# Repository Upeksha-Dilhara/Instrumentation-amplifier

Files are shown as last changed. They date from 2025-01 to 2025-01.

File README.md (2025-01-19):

# Instrumentation Amplifier for Thermocouple

This repository contains the design and implementation of an instrumentation amplifier tailored for thermocouple applications. The project was developed as part of the **EN3533 - Electronic Instrumentation** course at the **University of Moratuwa**. 

The goal of this project is to design an accurate and reliable instrumentation amplifier (IN-AMP) to amplify small voltage signals generated by thermocouples, ensuring precise temperature measurement. 
The amplifier is optimized to reject noise and maintain signal integrity in various industrial and scientific applications.

## Key Features
<p align="justify"> This project focuses on the amplification of weak thermoelectric signals generated by K-type thermocouples. The instrumentation amplifier design ensures effective noise rejection through a high common-mode rejection ratio (CMRR). It incorporates high input impedance, which allows for accurate readings without causing loading on the signal source. The printed circuit board (PCB) is optimized to minimize electromagnetic interference (EMI) and features precise signal routing. Additionally, the design includes a built-in cold-junction compensation mechanism for accurate temperature measurements. </p>

## Introduction
<p align="justify">Thermocouples are temperature sensors that operate based on the Seebeck effect, which generates a proportional voltage when there is a temperature difference between two dissimilar metals. K-type thermocouples, which are widely used in this project, are recognized for their wide temperature range (0°C to 1300°C), rugged design, and near-linear output voltage. To amplify the weak voltage signals generated by these thermocouples, instrumentation amplifiers (IN-AMPs) are used. These specialized amplifiers excel at amplifying small signals with high accuracy, rejecting noise and interference, and maintaining signal integrity through high input impedance and low output impedance. In thermocouple applications, where signals are often weak and susceptible to noise, an IN-AMP ensures reliable and precise amplification.</p>

## Specifications
- **Thermocouple Type**: K-type
- **Temperature Range**: 0°C to 1300°C
- **Output Voltage**: 0–55 mV
- **Sensitivity**: ~41 µV/°C
- **Selected IN-AMP**: AD8495
- **Amplifier Gain**: Fixed at 122 dB
- **Power Supply Voltage**: +5V
- **Output Sensitivity**: 5 mV/°C

## Design Process
### Schematic Design
<p align="justify">The schematic design involves several key components, including a thermocouple connector with ground shielding, the AD8495 instrumentation amplifier, and filtering components such as resistors and capacitors for noise rejection. Decoupling capacitors are placed near the power supply pins to ensure stable operation. Differential inputs are routed with equal PCB trace lengths for signal integrity, while noise filtering is achieved using carefully chosen RC networks. </p>

- Differential filter cutoff frequency: \( f_{\text{DIFF}} = \frac{1}{2 \pi R (2C_D + C_C)} \)
- Common-mode filter cutoff frequency: \( f_{\text{CM}} = \frac{1}{2 \pi R C_C} \)


### PCB Design
<p align="justify">The PCB design employs a two-layer board measuring 22mm by 33mm. The top layer is allocated for power lines with a width of 20 mil and signal tracks with a width of 10 mil, while the bottom layer serves as a ground plane to minimize EMI. Components are strategically positioned close to the thermocouple connections to ensure accurate cold-junction compensation. Differential pair routing is utilized for positive and negative input signals, and the design was verified using Altium's design rule checker. The PCBs were manufactured by JLCPCB.</p>





<p align="justify">The fabrication adhered to specific constraints, including a minimum trace width of 10 mil, a minimum via diameter of 20 mil, and a minimum track spacing of 10 mil. Components were sourced from Mouser Electronics and assembled manually using soldering tools, ensuring high-quality construction of the PCB.</p>

## Testing and Results
- **Testing Environment**:
  - Ambient temperature conditions.
  - K-type thermocouple connected to a controlled heat source.
- **Key Metrics**:
  - Noise rejection validated using a signal generator and oscilloscope.
  - Output voltage measured across a range of temperatures.
  - Results matched expected sensitivity of 5 mV/°C.
- **Observations**:
  - High stability and accuracy in measurements.
  - Effective noise rejection in noisy industrial-like environments.

For further details, refer to the [Instrumentation_Amplifier_for_thermo_couple_Report.pdf](https://github.com/user-attachments/files/18468705/Instrumentation_Amplifier_for_thermo_couple_Report.pdf)

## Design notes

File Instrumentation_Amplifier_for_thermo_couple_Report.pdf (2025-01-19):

### Department of Electronic and Telecommunication Engineering

## University of Moratuwa, Sri Lanka

## EN3533 - ELECTRONIC INSTRUMENTATION

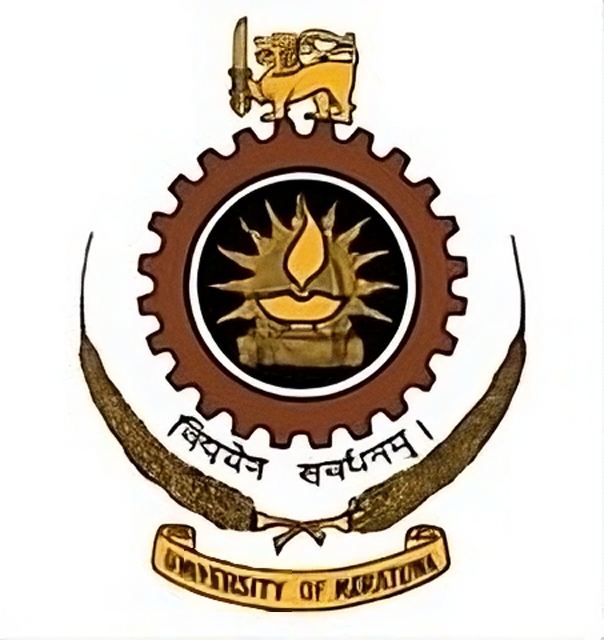
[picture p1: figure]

# Instrumentation Amplifier for Thermo-couple

# Group Members

DILHARA A.D.U | - | 200128D
FERNANDOPULLE N.K - | 200172F
SHEHAN H.M.K | - | 200601X

# Contents

## 0.1 Introduction

In this project, we have designed an Instrumentation amplifier specifically tailored for thermocouple applications. The report provides a comprehensive overview, including basic information about thermocouples and instrumentation amplifiers. It outlines the meticulous design process, encompassing component selection, amplifier configuration, and testing procedures employed to achieve accurate amplification of thermoelectric signals. The report also includes detailed schematics, PCB layouts, and insights into the amplifier selec-

tion process, offering readers a holistic understanding of the project.

### 0.1.1 Thermocouples and applications

Thermocouples are temperature sensors widely used in various industrial, scientific, and commercial applications due to their reliability and simplicity. Operating principle of thermocouples based on the Seebeck effect, where a temperature difference between two dissimilar metals generates a voltage proportional to the temperature change. The subtopic covers different types of thermocouples, such as K-type, J-type, and T-type, each suited for specific temperature ranges and environments.

Real-world applications of thermocouples are explored, ranging from industrial processes and HVAC systems to aerospace and scientific research. Detailed examples illustrate how thermocouples are utilized in diverse settings, showcasing their adaptability and effectiveness in measuring temperatures under varying conditions.

### 0.1.2 Introduction to Instrumentation amplifiers

Instrumentation amplifiers (In-amps) are specialized operational amplifiers (op-amps) designed to amplify small signals with high precision and accuracy, particularly in noisy environments. Unlike general-purpose op-amps, instrumentation amplifiers are specifically engineered for applications where signal integrity is critical, such as in sensor measurements and data acquisition systems.
What sets instrumentation amplifiers apart is their ability to provide high input impedance, high common-mode rejection ratio (CMRR), and low output impedance. These characteristics make them ideal for amplifying weak signals while rejecting common-mode noise, ensuring that the amplified output accurately represents the desired signal.
Instrumentation amplifiers typically consist of multiple operational amplifiers and precision resistors configured in specific ways to achieve high performance. They offer differential inputs, allowing the amplification of the voltage difference between two input signals. In-amps are commonly used in various fields, including industrial automation, medical instrumentation, and scientific research, where accurate measurement of small signals is crucial.

### 0.1.3 Need for an INAMP in thermo-couple applications

In thermocouple-based applications, accurate temperature measurement is paramount. Thermocouples generate small voltage signals proportional to temperature changes, which are susceptible to interference and noise. Instrumentation amplifiers play a crucial role by precisely amplifying these weak signals while rejecting common-mode noise. Their high input impedance and excellent common-mode rejection properties ensure the fidelity of temperature readings, making them indispensable in thermocouple circuits. By enhancing signal integrity, instrumentation amplifiers enable reliable and precise temperature measurements, making them essential components in thermocouple-based systems used across various industries and scientific research.

## 0.2 Thermo-couple Specifications

### 0.2.1 Operating Principles and Parameters

A thermocouple is a device made by two different wires joined at one end, called junction end or measuring end. The two wires are called thermoelements or legs of the thermocouple: the two thermoelements are distnguished as positive and negative ones. The other end of the thermocouple is called tail end or reference end (Figure1). The junction end is immersed in the enviroment whose temperature T2 has to be measured, which can be for instance the temperature of a furnace at about 500°C, while the tail end is held at a different temperature T1, e.g. at ambient temperature.

Figure 1: Schematic drawing of a thermo-couple

Because of the temperature difference between junction end and tail end a voltage difference can be measured between the two thermoelements at the tail end: so the thermocouple is a temperature-voltage transducer.

However, it can be understood that the Emf depends on both T1 and T2: as T1 and T2 can change indipendently, a monotonic Emf vs T2 relationship cannot be defined if the tail end temperature is not constant. For this reason the tail end is mantained in an ice bath made by crushed ice and water in a Dewar flask: this produces a reference temperature of 0°C. All the voltage versus temperature relationships for thermocouples are referenced to 0°C. In a thermo-couple, measuring end is called as Hot junction and the tail end (reference junction) is called as Cold junction.

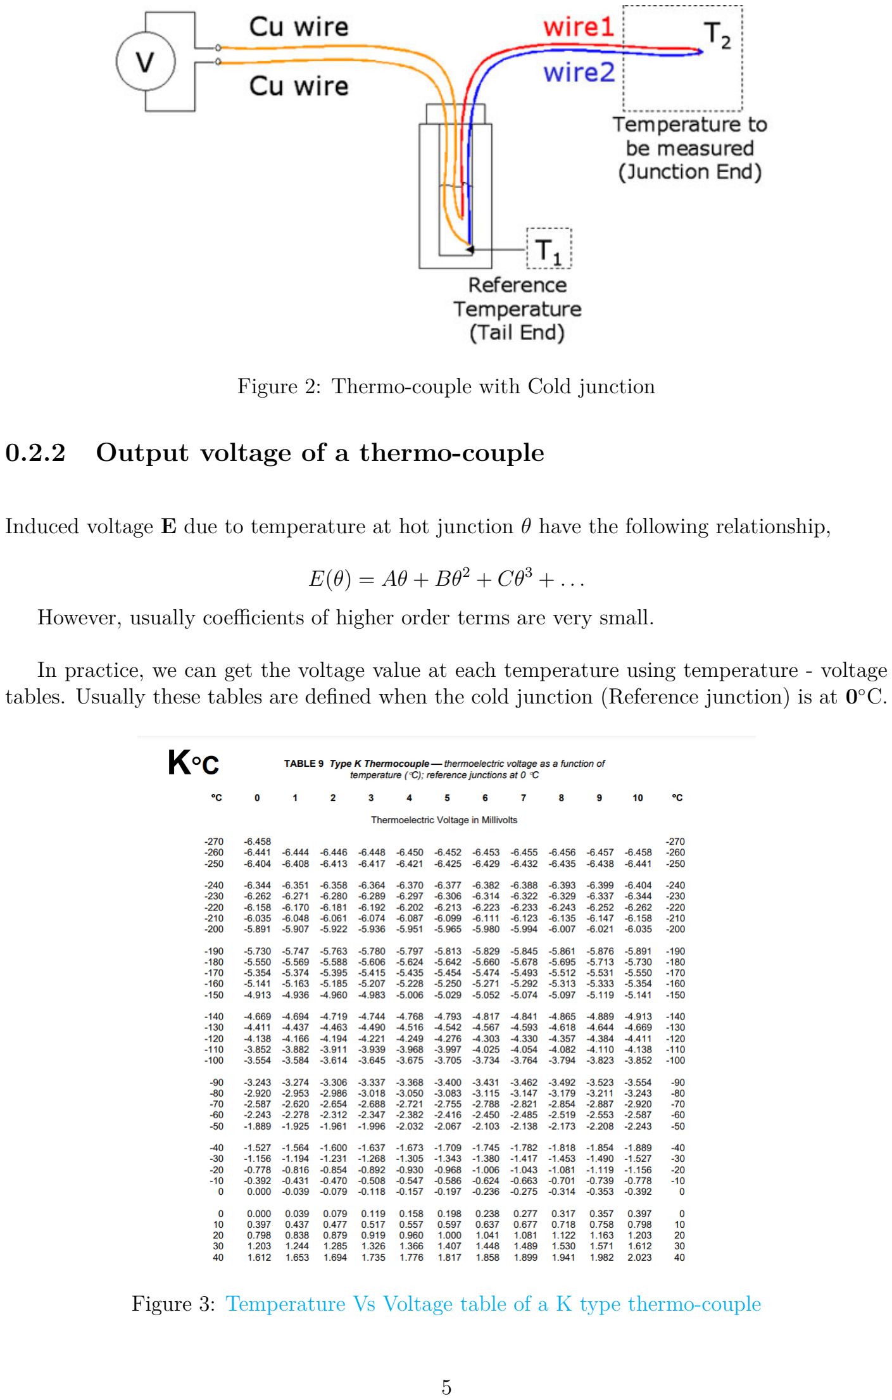
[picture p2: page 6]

Figure 2: Thermo-couple with Cold junction

### 0.2.2 Output voltage of a thermo-couple

Induced voltage E due to temperature at hot junction θ have the following relationship,

E(θ) = Aθ + Bθ² + Cθ³ + . . .

However, usually coefficients of higher order terms are very small.

In practice, we can get the voltage value at each temperature using temperature - voltage tables. Usually these tables are defined when the cold junction (Reference junction) is at 0

◦C.

Figure 3: Temperature Vs Voltage table of a K type thermo-couple (https://www.pyromation.com/downloads/data/emfk_c.pdf)

### 0.2.3 Selection of a thermo-couple

For our design, we have selected K Type thermo-couple due to its wide range of temperatures. One of the major advantage of K type thermocouple over other thermocouple’s is it can function in rugged environmental condition & in various atmospheres. Two wires of K type thermocouple are made from Alumel and Chromel alloys.

Another major importance is output voltage of K type thermocouple is almost linear with the temperature. (Linearity)

Specifications of K type thermo-couple

- Temperature Range | - 0 to 1300◦C (Can be used for negative temperatures also)
- Output voltage | - 0 to 55 mV
- Sensitivity | - Approximately 41µV/◦C

## 0.3 Instrumentation Amplifiers

Instrumentation amplifiers (Referred as IN-AMP) are specialized operational amplifiers that play a pivotal role in enhancing the accuracy and reliability of thermocouple measurements. By precisely amplifying weak thermoelectric signals while rejecting common-mode noise, these amplifiers ensure the fidelity of temperature data.

### 0.3.1 Operation of IN-AMPS

Three operational amplifiers (Op-Amps) and a number of precisely arranged resistors are needed to operate an instrumentation amplifier in order to produce the required amplification characteristics. An IN-AMP typically has three stages in its configuration:

- Differential Amplifier Stage: Two inputs receive the input signal differently. An initial differential amplifier that amplifies the voltage difference between these inputs is typically used in the first stage.
- Buffer Stages: After the differential amplifier are two buffer amplifiers, which are frequently constructed using operational amplifiers. Gain adjustment, low output impedance, and high input impedance are all made possible by these buffers. Additionally, they improve the overall performance by enabling the isolation of the gain-setting resistors from the source impedance.
- Gain Control: External precision resistors are usually used to set the gain of the IN-AMP and can be adjusted based on the needs of the application.

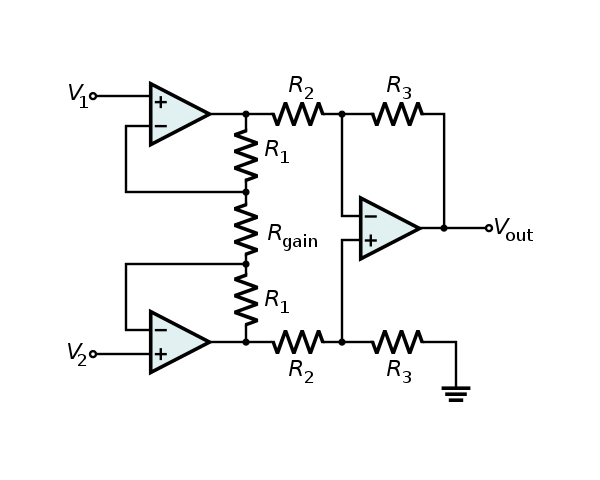
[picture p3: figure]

Figure 4: Basic Instrumentation amplifier

Since operational amplifiers normally have very high input impedance, two OP-amps at the input provides very high input impedance. Output voltage is given by ,

Vout =

1 +

2R1

Rgain !
R3
R2

By adjusting the Rgain properly, we can control the gain of the instrumentation amplifier.

### 0.3.2 Signal Conditioning using IN-AMP

Signal conditioning using instrumentation amplifiers (IN-AMPS) is a crucial aspect in various fields where precise signal manipulation is necessary to enhance the accuracy of measurements or sensor data.

- Amplification and Gain Control

With their high differential gain and ability to precisely magnify the difference between two input signals, IN-AMPS are invaluable tools for amplifying weak signals. The simplicity of gain control, which is accomplished by using external resistors, is their main feature. Because of its adaptability, amplification can be customized to meet the needs of individual applications, guaranteeing accurate and regulated signal enhancement.

- Noise Rejection

The remarkable ability of IN-AMPS to reject common-mode noise is a crucial component. They are excellent at reducing noise or interference that is equally present on both inputs while enhancing the differences between the input signals. This ability to reject noise is essential in applications where the signal of interest is frequently overshadowed by background noise.

- Filtering and Conditioning

IN-AMPS can be easily combined with other circuitry to offer conditioning and filtering of signals. By combining resistors, capacitors, and filters, they effectively cut out undesirable frequencies and modify the circuit response to fit the particular requirements of the application.

- High Input Impedance

Because of their high input impedance and low current consumption, IN-AMPS shield the signal source from loading effects. This quality guarantees precise measurements, which is critical in many applications where accuracy is critical.

- Precision Measurements

IN-AMPS are essential for sensor data acquisition applications like strain gauges, temperature, pressure, and bio-signal monitoring. They precisely boost these tiny sensor signals, improving measurement accuracy and dependability.

- Data Acquisition Systems

Before analog-to-digital conversion, signals gathered from a variety of sensors are conditioned by IN-AMPS, which are essential parts of data acquisition systems. Their involvement affects the dependability and quality of the collected data by guaranteeing the optimization of signals for precise and accurate digital representation.

### 0.3.3 Design requirements

In order to make our thermocouple measurement system effective and competitive, we looked at existing temperature controllers in the market. By understanding their features, we established specific design needs for our project. These requirements act as our project’s foundation, guiding us to create a system that meets user expectations and industry standards. We mainly referred the Omoron temperature controllers datasheets to get an idea for design requirements.

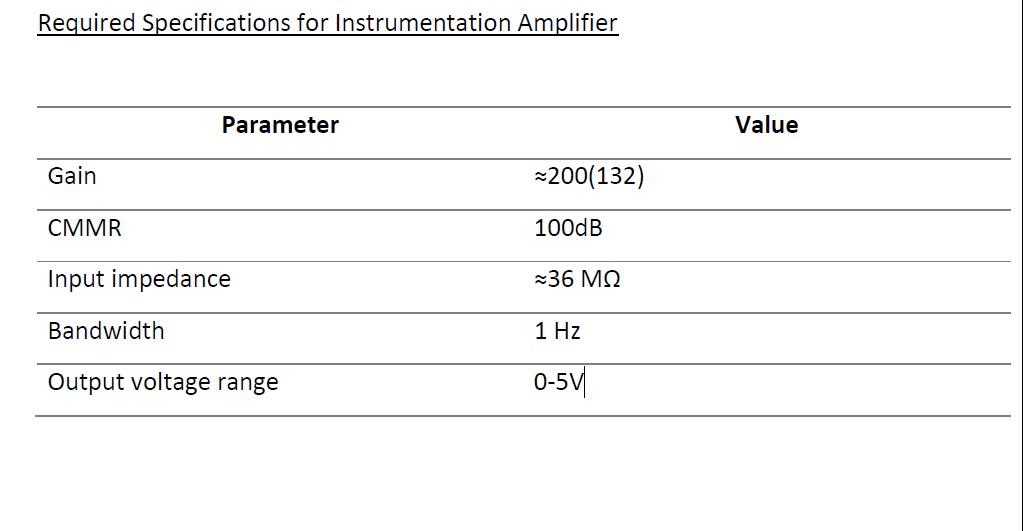
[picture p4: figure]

Figure 5: Requirements for the IN-AMP

### 0.3.4 Selection of a IN-AMP for the design

For the selection of an instrumentation amplifier (IN-AMP) for our design project, each of our group members individually researched and identified several op-amp ICs. The ICs we considered for our project include the AD8495, AMP04, and INA821. To determine the best IC for our instrumentation amplifier, we established specific criteria and assigned marks to each IC based on those criteria. The table below summarizes the marks obtained by each IC.

### Selection criteria

1. Input voltage range
2. Output voltage range
3. Gain
4. Input Impedance
5. CMRR
6. Bandwidth

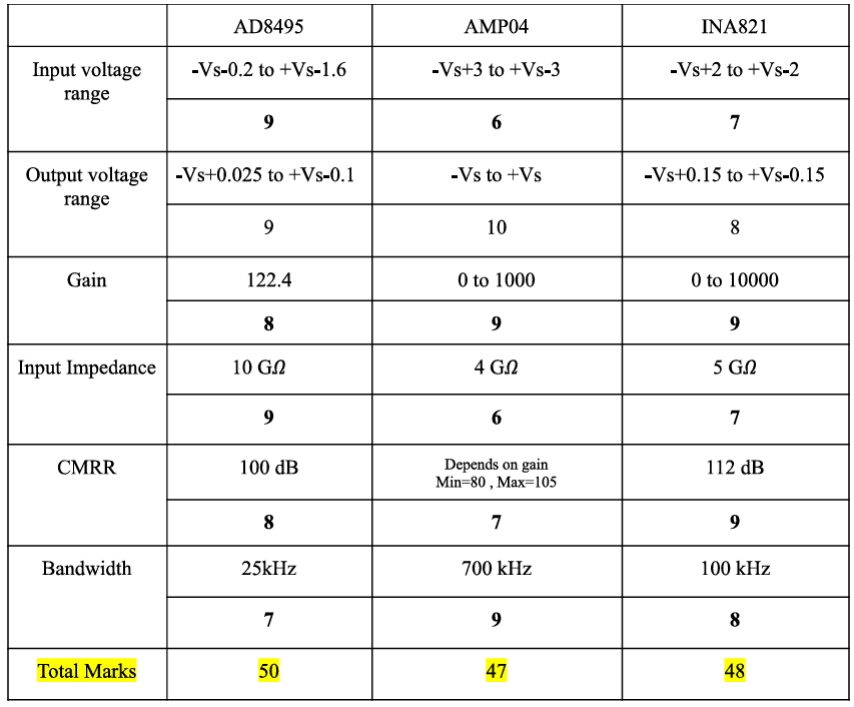
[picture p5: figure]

Figure 6: Selection criteria for IN-AMP selection

### Grounding and Shielding recommendations

In order to select the best IC for our design, we also considered the grounding and shielding recommendations given in the datasheet of each IC. By adhering to these guidelines, we can confidently anticipate optimal performance, minimal interference, and overall reliability in our final design.

Criterion | AD8495 | AMP04 | INA821
Grounding | Given properly with diagrams, Single ground is suffient at input to avoid ground loops. | Not properly mentioned | Provided proper component placement. But no much detail about grounding practices.
Shielding | Ground planes and power planes have been used in layouts. | Recommends to use shielded cables at input , twisted pairs | Recommends to keep proper trace spaces
Recommend Layouts | Evaluation board for the IC are available by same manufacturer. It can be used as reference. | Not given | Provided recommend layout practices and component placement guidline
Marks | 9 | 5 | 8

Table 1: Selection criteria for IN-AMP selection

By considering the Marks allocated in the selection Matrix and the best grounding and shielding methods given in the datasheets, AD8495 is the selected best Instrumentation amplifier for our thermocouple application.

## 0.4 Design Process

In the Design Process section, we outline the systematic approach undertaken to create our thermocouple measurement system. Above established guidelines and considering the specific requirements of the selected thermocouple and instrumentation amplifier, this phase focused on meticulous schematic design and precise PCB layout. By adhering to these guidelines, our team ensured the integration of key components for accurate and reliable temperature measurements. For the Schematic and PCB design, we used Altium PCB designer software.

### 0.4.1 Schematic Design

In the schematic design, our focus was on translating theoretical concepts into a practical and functional circuit. Guided by the unique requirements of our selected thermocouple and instrumentation amplifier.

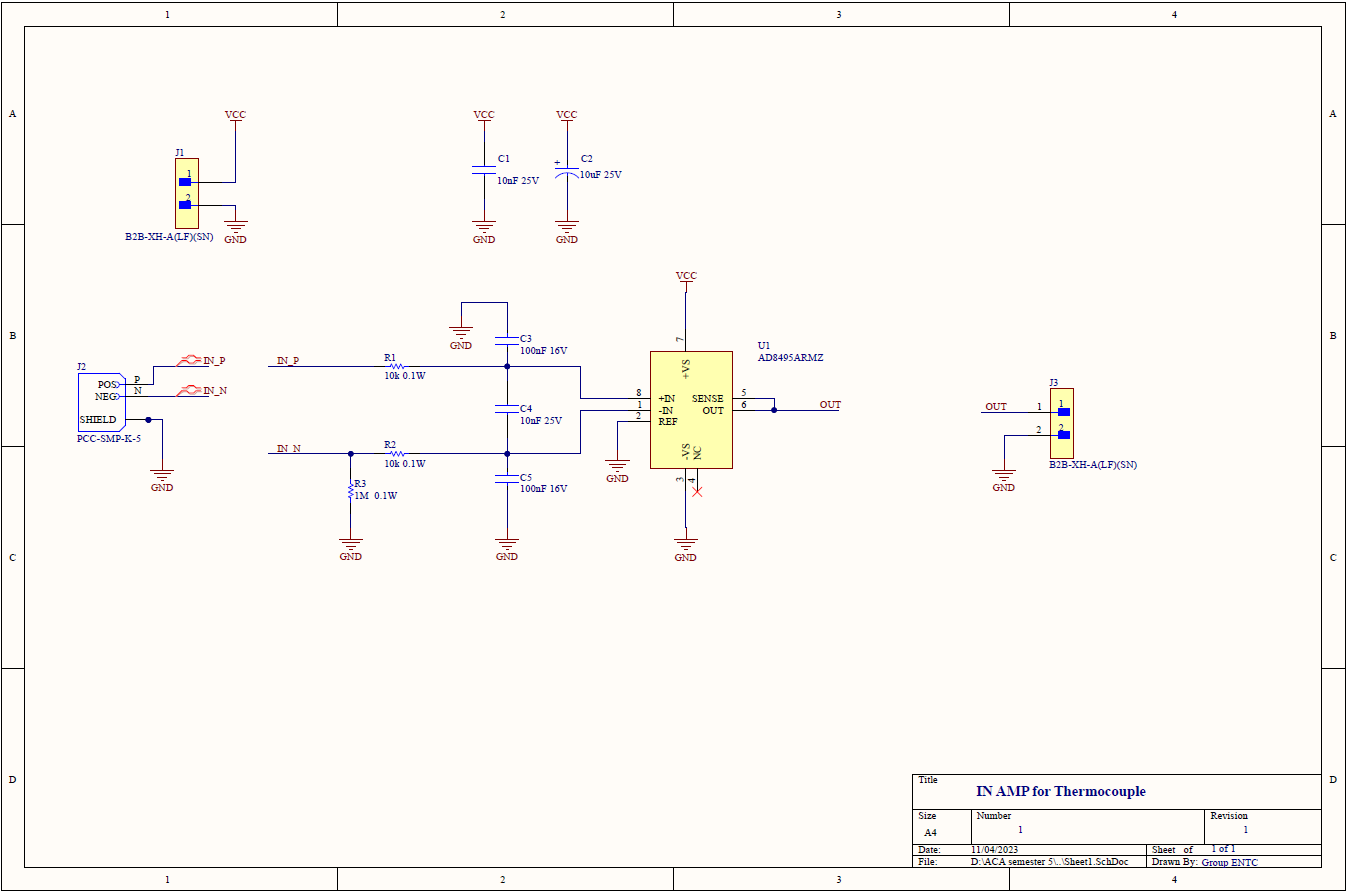
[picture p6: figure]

Figure 7: Schematic design for the IN-AMP

Component description and Signal flow

- J1 - Power connector (JST 2 pin connector)
- J2 - Thermo-couple connector with ground connection for shielding
- J3 - Output connector (JST 2 pin connector)

Nets assigned for J3 input pins are defined as Differential inputs to ensure the both PCB tracks of positive and negative input are equal length.

In AD8495 instrumentation amplifier data sheet, they have provided the recommend schematic for basic applications of the IC.

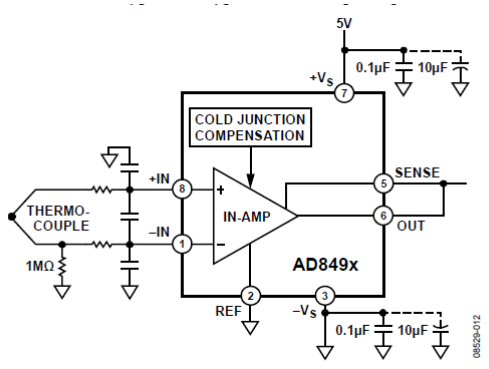
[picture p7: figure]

Figure 8: Basic connection given in data sheet of AD8495 IC

C1 and C2 are coupling capacitors to clean power supply voltage at +Vs pin of AD8495. R1,R2,C3,C4 and C5 at the input perform a filtering operation to filter out the common mode and differential mode noise at the input.

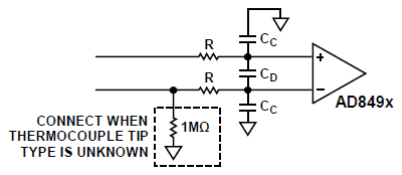
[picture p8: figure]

Figure 9: Filters at the input

When we set R1 = R2 = R and C3 = C5 = Cc and C4 = CD , filter frequencies are given by ,

fDIF F =

1
2πR(2CD + Cc)
and ,

fCM =

1
2πRCc
where CD ≥ 10Cc .

R3 is a 1MΩ resistor which is connected to negative input of the thermo-couple connector and ground. It helps to detect any thermo-couple breakdown condition by putting the output to rail high in an open thermocouple condition.

Output voltage of the circuit has a sensitivity of 5mV/◦C and it is given by,

VOUT = (TMJ × 5mV/◦C) + VREF

where TMJ is the measuring junction temperature in Celsius and VREF is the voltage at Reference pin of AD8495. We have grounded the reference pin.

Internal structure of AD8495

AD8495 includes a 3 op amp configuration described in the section Instrumentation Amplifiers with temperature sensing unit for cold junction compensation. RG, gain adjustment resistor is fixed internally as in the block diagram, so it has a fixed gain of 122dB.

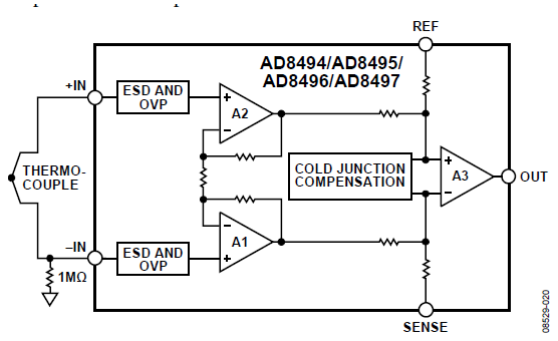
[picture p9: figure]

Figure 10: Block diagram of AD8495

### 0.4.2 PCB Design

In the PCB Design section, we outline the meticulous process of translating our circuit schematic into a physical, manufacturable board. Guided by the principles of signal integrity, noise reduction, and shielding techniques. We have designed a two layer PCB of 22mm × 33mm in dimension.

- Top layer - Power lines (VCC, width = 20mil ) and signal tracks (Width = 10mil).
- Bottom layer - Ground

Connecting the whole bottom layer to ground minimizes loop areas and reduces EMI between signal tracks.

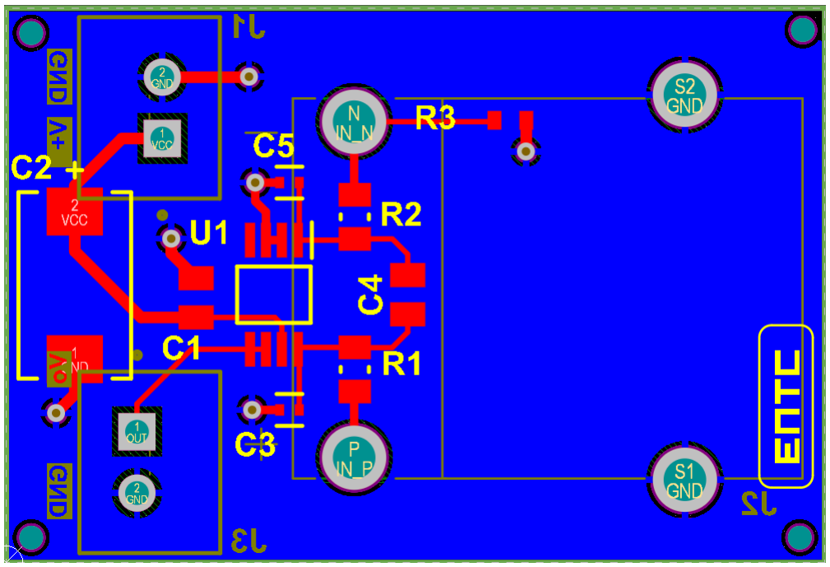
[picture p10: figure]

Figure 11: PCB Layout

All the connectors (J1,J2 and J3) are on the bottom side of the PCB and components are on the top side. To operate the cold junction compensation unit of AD8495, it is important to place the IC as close as possible to cold junction of the thermocouple. Decoupling capacitors are placed near to +V s pin of the IC. Also positive and negative input nets of the thermo-couple connector (J3) are routed using Differential pair routing.

Design for manufacturing considerations

We imported the printed PCB’s from china JLC PCB (https://jlcpcb.com/) company. According to their capabilities of manufacturing process, we set the design rules and finally run the design rule check process in altium software to ensure the correctness.

| JLC capability | In the design
Minimum trace width | 5mil | 10mil
Minimum Via diameter | 20mil | 20mil
Minimum track spacing | 5mil | 10mil

Table 2: Design considerations

Top Layer

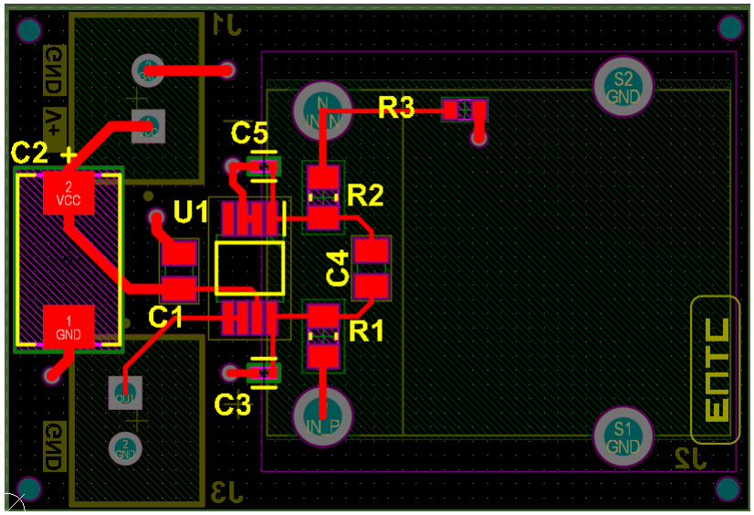
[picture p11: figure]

Figure 12: Top layer of the PCB

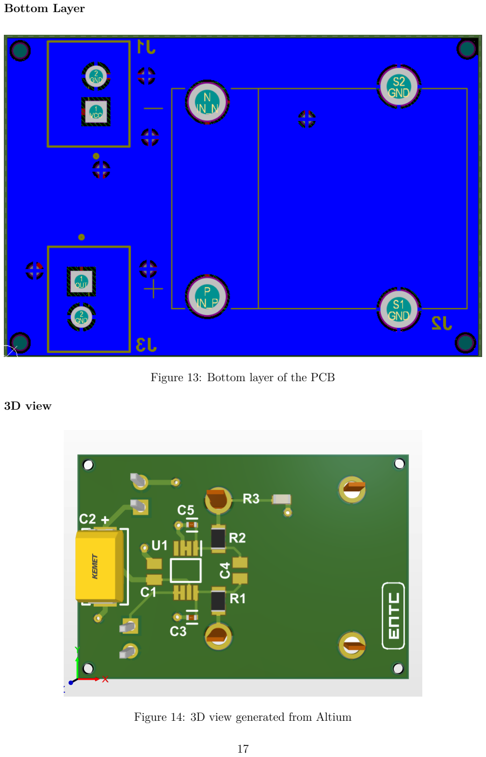
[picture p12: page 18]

Bottom Layer

Figure 13: Bottom layer of the PCB

3D view

Figure 14: 3D view generated from Altium

## 0.5 Bill of Materials

Comment | Designator | Footprint | Quantity
10nF 25V | C1, C4 | CAPC2012X88N | 2
10uF 25V | C2 | FP-T491D-MFG | 1
100nF 16V | C3, C5 | FP-C1005-050-0 05-MFG | 2
B2B-XH-A(LF)(SN) | J1, J3 | FP-B2B-XH-A LF SN-MFG | 2
PCC-SMP-K-5 | J2 | OMEGA PCC-SMP-K-5 | 1
10k 0.1W | R1, R2 | RESC2013X60X35NL10T20 | 2
1M | R3 | RESC1608X55X25LL10T15 | 1
AD8495ARMZ | U1 | SOP65P490X110-8N | 1

Table 3: Bill of materials

We ordered these components from Mouser electronics. (https://www.mouser.com/)

# References

[1] Thermocouples: The Operating Principle Thermocouples Operating Principles. Available at: Here (https://www.msm.cam.ac.uk/utc/thermocouple/pages/ThermocouplesOperatingPrinciples.html)
[2] Precision thermocouple amplifiers with cold junction compensation data ... Available at: DATASHEET (https://www.analog.com/media/en/technical-documentation/data-sheets/ad8494_8495_8496_8497.pdf)
[3] C table 9 type K thermocouple thermoelectric voltage as a ... - pyromation. Available at:Here (https://www.pyromation.com/downloads/data/emfk_c.pdf)

***END***

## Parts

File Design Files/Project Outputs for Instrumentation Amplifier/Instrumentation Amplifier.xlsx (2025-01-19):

Comment | Description | Designator | Footprint | LibRef | Quantity
10nF 25V | AECQ200 automotive qualif | C1, C4 | CAPC2012X88N | C0805C103K8RACAUTO | 2 | Done
10uF 25V | CAP TANT 10UF 10% 25V 2917 | C2 | FP-T491D-MFG | T491D106K025ATAUTO | 1 | Done
100nF 16V | Multilayer Ceramic Capacitors 100nF ±10% 16V X7R SMD 0402 | C3, C5 | FP-C1005-050-0_05-MFG | C1005X7R1C104K050BC | 2 | Done
B2B-XH-A(LF)(SN) | CONN HEADER VERT 2POS 2.5MM | J1, J3 | FP-B2B-XH-A_LF_SN-MFG | CMP-2000-05888-3 | 2 | No
PCC-SMP-K-5 | Thermocouple Conn, K Type, Rcpt, Pk 5 | J2 | OMEGA_PCC-SMP-K-5 | PCC-SMP-K-5 | 1 | No
10k 0.1W | Chip Resistor, 10 KOhm, +/- 1%, 0.125 W, -55 to 155 degC, 0805 (2012 Metric), RoHS, Tape and Reel | R1, R2 | RESC2013X60X35NL10T20 | RC0805FR-0710KL | 2 | Done
1M 0.1W | Chip Resistor, 1 MOhm, +/- 1%, 100 mW, -55 to 155 degC, 0603 (1608 Metric), RoHS, Tape and Reel | R3 | RESC1608X55X25LL10T15 | RC0603FR-071ML | 1
AD8495ARMZ | Precision Thermocouple Amplifiers | U1 | SOP65P490X110-8N | AD8495ARMZ | 1
